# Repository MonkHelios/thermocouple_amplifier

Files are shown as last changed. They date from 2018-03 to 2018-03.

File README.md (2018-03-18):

# thermocouple_amplifier
Thermocouple amplifier circuit(s) for interfacing with microcontrollers. 

1. J and K type thermocouple amplifier circuit built around LTC2053 instrumentation amplifier and LT1025 cold junction compensator.
   This breakout board has analog output of X mV/degC (yet to be tested). Initially feeding it to the ADC chanel of an arduino UNO.

Project link : https://hackaday.io/project/67584-thermocouple-amplifier-for-arduino-and-other-mcu

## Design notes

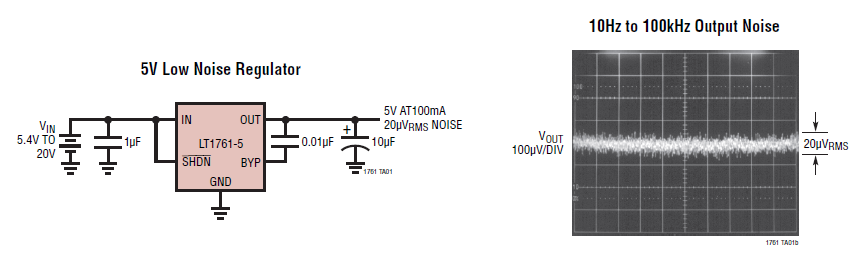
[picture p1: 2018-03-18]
reference datasheets and schematics/vreg.png

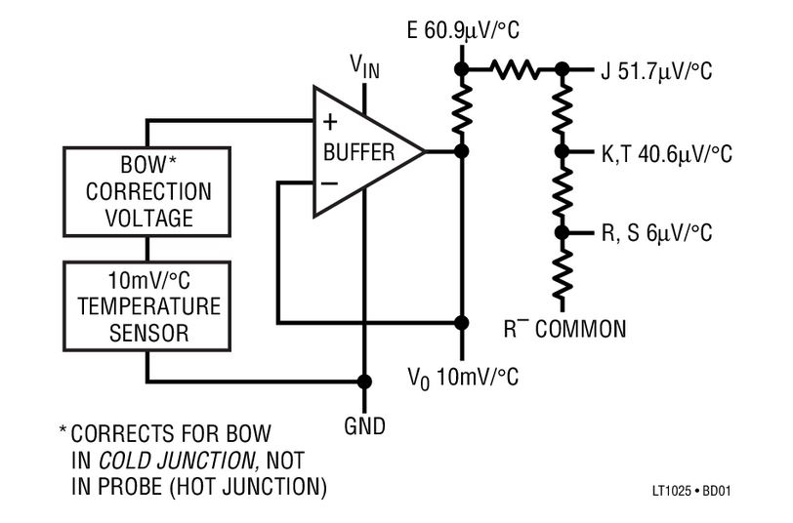
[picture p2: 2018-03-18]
reference datasheets and schematics/lt1025.jpg

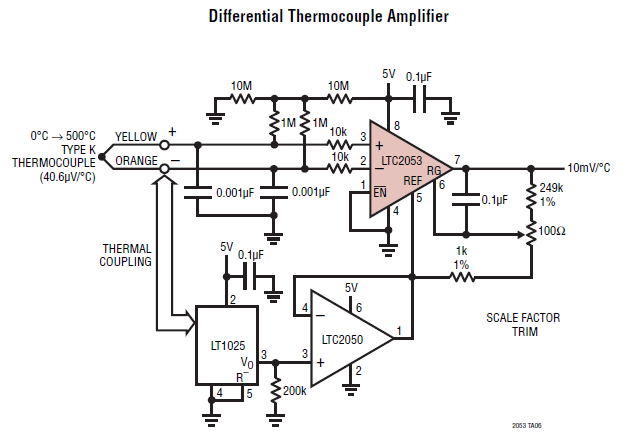
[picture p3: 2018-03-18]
reference datasheets and schematics/amplifier.png

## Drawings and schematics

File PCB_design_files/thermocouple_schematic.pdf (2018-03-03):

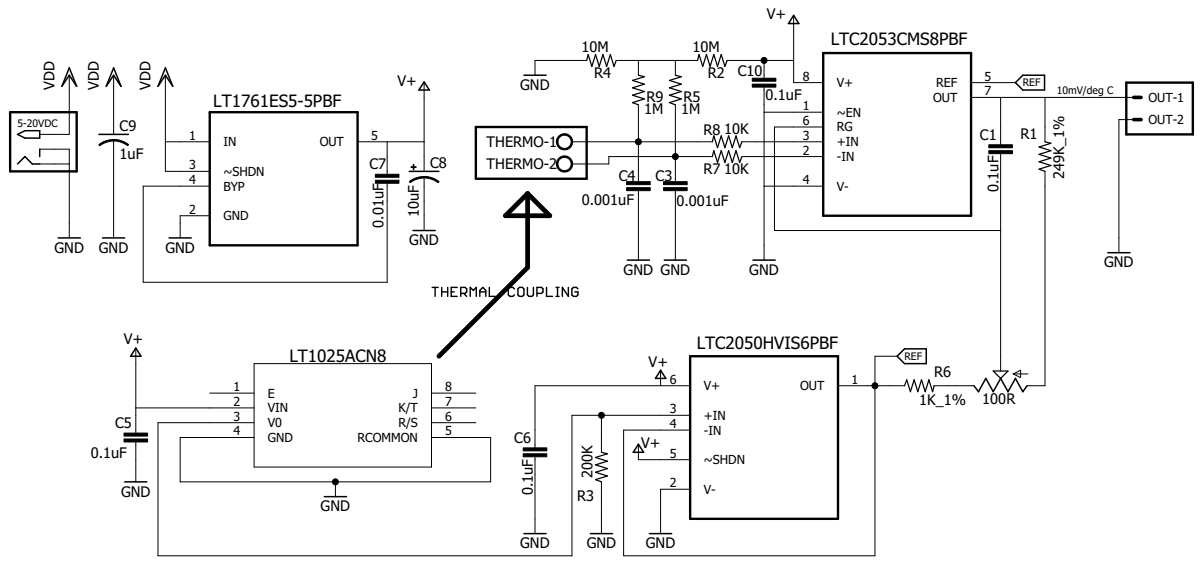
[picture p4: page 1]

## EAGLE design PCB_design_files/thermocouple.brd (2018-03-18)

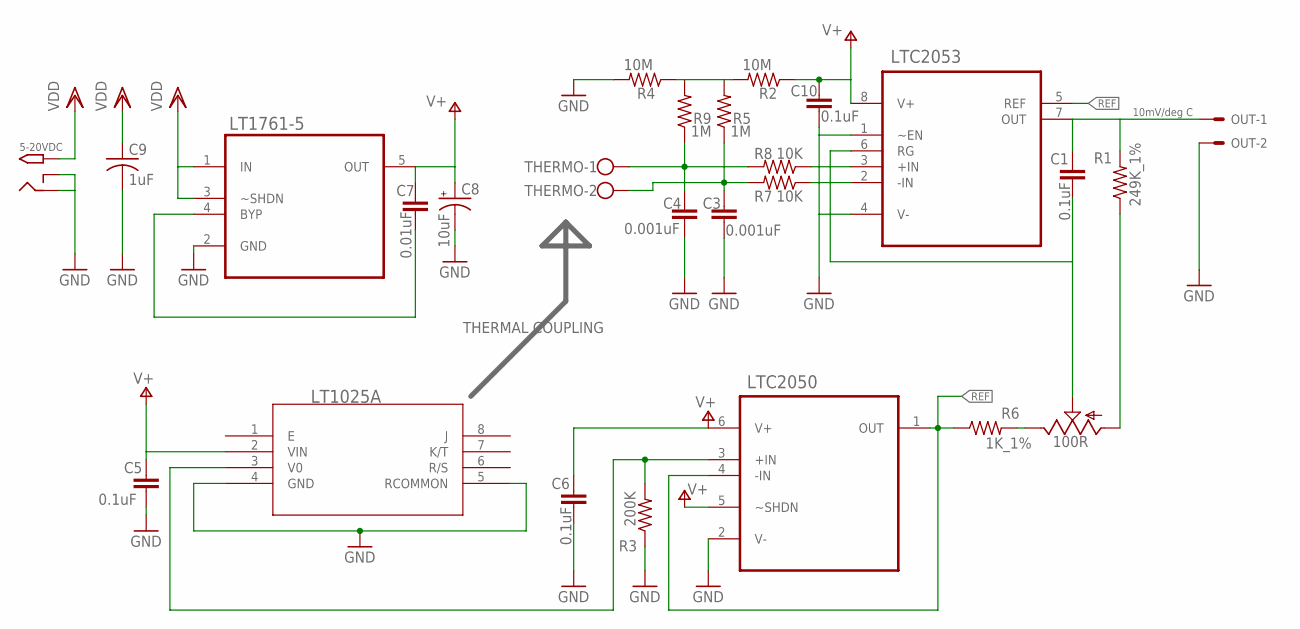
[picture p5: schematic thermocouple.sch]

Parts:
5-20VDC: DC_IN; PJ-102A
C1, C5, C6, C10: 0.1uF; C0805
C3, C4: 0.001uF; C0805
C7: 0.01uF; C0805
C8: 10uF; E2,5-6E
C9: 1uF; C0805
OUT: 10mV/C; 6410-02
POT: 100R; 6MM
R1: 249K_1%; R0805
R2, R4: 10M; R0805
R3: 200K; M0805
R5, R9: 1M; R0805
R6: 1K_1%; R0805
R7, R8: 10K; R0805
THERMO: W237-102
U1: LT1025A; PDIP-8_N
U2: LTC2053; SOP65P490X110-8N
U3: LTC2050; SOT95P280X100-6N
U4: LT1761-5; SOT95P280X100-5N

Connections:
GND: 5-20VDC.RING, 5-20VDC.RING_SW, C3.1, C4.2, C5.2, C6.2, C8.-, C9.2, C10.1, OUT.2, R3.1, R4.2, U1.4 (GND), U1.5 (RCOMMON), U2.1 (~EN), U2.4 (V-), U3.2 (V-), U4.2 (GND)
unnamed: C1.2, POT.S, U2.6 (RG)
unnamed: C1.1, OUT.1, R1.2, U2.7 (OUT)
unnamed: POT.A, R1.1
unnamed: R2.2, R4.1, R5.2, R9.2
unnamed: R7.1, U2.2 (-IN)
unnamed: R8.1, U2.3 (+IN)
unnamed: C3.2, R5.1, R7.2, THERMO.2
unnamed: C4.1, R8.2, R9.1, THERMO.1
unnamed: R3.2, U1.3 (V0), U3.3 (+IN)
unnamed: C7.2, U4.4 (BYP)
unnamed: POT.E, R6.2
REF: R6.1, U2.5 (REF), U3.1 (OUT), U3.4 (-IN)
V+: C5.1, C6.1, C7.1, C8.+, C10.2, R2.1, U1.2 (VIN), U2.8 (V+), U3.5 (~SHDN), U3.6 (V+), U4.5 (OUT)
VDD: 5-20VDC.TIP, C9.1, U4.1 (IN), U4.3 (~SHDN)

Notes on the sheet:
10mV/deg C
THERMAL COUPLING

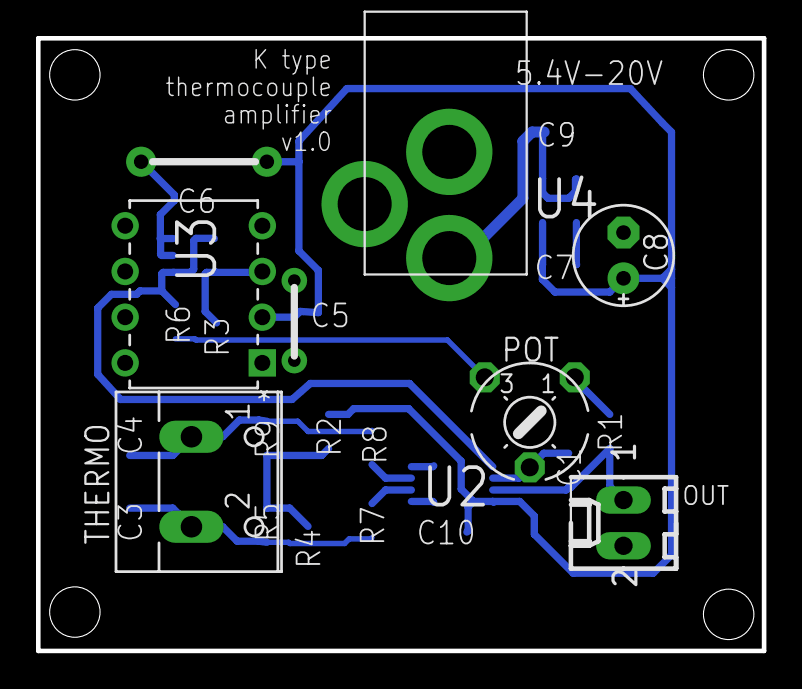
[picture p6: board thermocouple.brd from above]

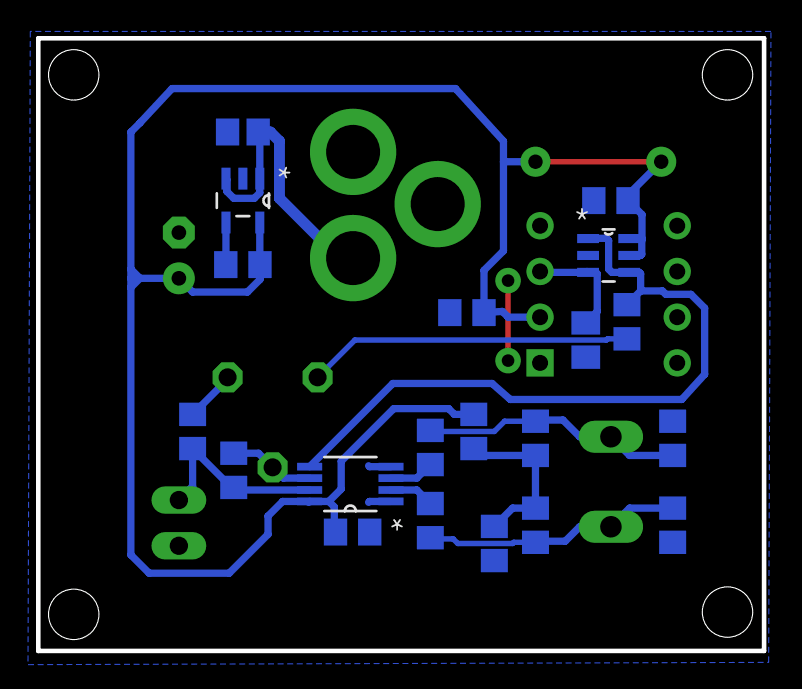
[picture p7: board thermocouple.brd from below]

Board: 2 copper layers, 40.3 x 34.0 mm, 26 parts (20 on the bottom side), 15 nets.

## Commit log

2018-03-03 first board files
    [thermocouple.brd, thermocouple.sch]
2018-03-18 new folder for pcb files
2018-03-18 board files
    [thermocouple.brd, thermocouple.sch]
2018-03-18 gerbers for home fabrication
